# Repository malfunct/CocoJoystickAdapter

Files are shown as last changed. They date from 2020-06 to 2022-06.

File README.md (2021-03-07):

# CocoJoystickAdapter
Adapter to connect USB devices, such as gamepad or mouse,  to Tandy Color Computer joystick port.

Gerbers for shield PCB available in Shield Eagle Project directory. I have used https://jlcpcb.com/ to produce the boards in the past but any board house should be fine.

Components for the shield are listed in PartsList.txt

Arduino code for wireless xbox 360 controllers using wireless xbox 360 USB dongle is in the XBOX_360_wireless_arduino_code directory

Arduino code for wired xbox 360 controllers is in the XBOX_360_arduino_code directory

Make sure you have the libraries listed in Dependencies.txt installed for your Arduino IDE as well as configuring it for Arduino Uno R3 then open the correct ino file (wired or wireless) to match the controller you plan to use and compile and push to your Arduino Uno R3.

I assemble the shields with arduino on the bottom, USB sheild next and Coco Joystick shield on top. I power the arduino through the USB-B connector on the R3 board, plug my xbox controller into the USB sheild and use a straight through 6 pin din to 6 pin din cable to connect the adapter to the coco. A Commodore IEC cable works well for this purpose and are easy to find pre-built.

Have fun with your Coco!

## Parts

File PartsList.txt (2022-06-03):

1 - 61PC6F female DIN-6 connector
1 - TLP222A-2 dual solid state relay
1 - MCP4922 dual channel 12bit DAC with SPI
1 - 0.1uF ceramic capcitor
2 - 130 ohm 1/8 watt resistor
1 - 14 pin DIP socket
1 - 8 pin DIP socket
2 - 6 pin single row arduino stackable shield header
2 - 8 pin single row arduino stackable shield header
1 - Arduino Uno R3 (or clone)
1 - Keyes USB Host Shield https://www.fasttech.com/product/1144300-keyes-usb-host-shield-for-arduino (other brands did not work for me)

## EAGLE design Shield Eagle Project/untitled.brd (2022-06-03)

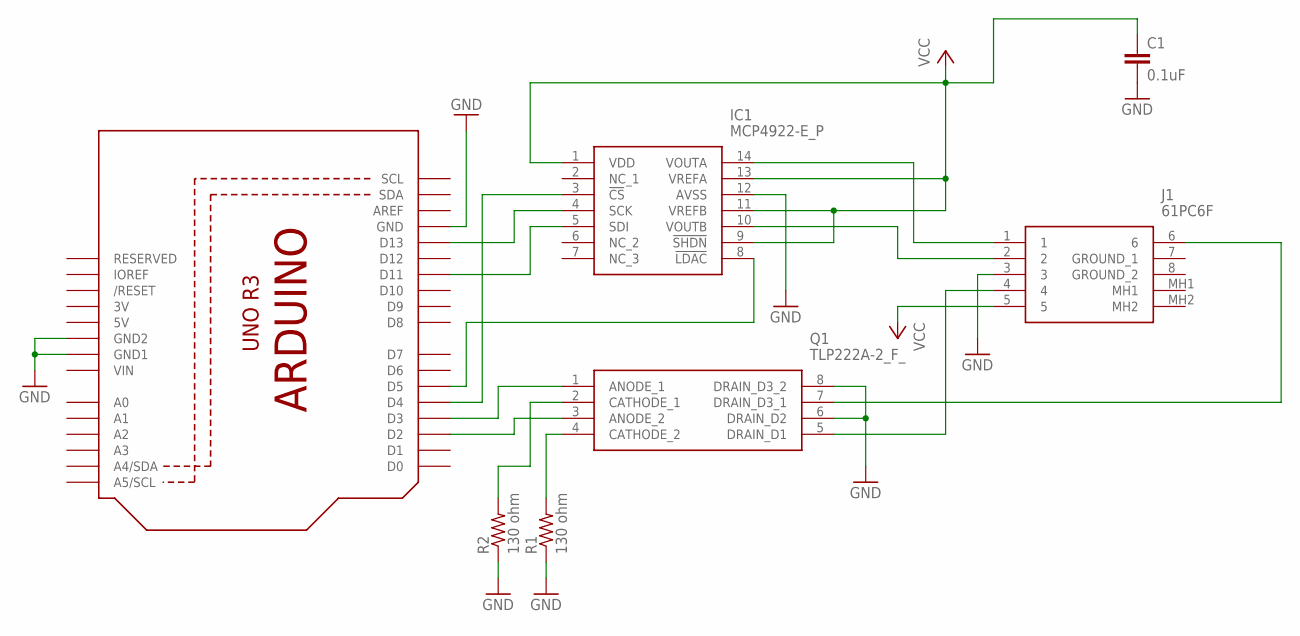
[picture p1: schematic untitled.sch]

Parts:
C1: 0.1uF; C050-024X044
IC1: MCP4922-E_P; DIP794W56P254L1905H432Q14N
J1: 61PC6F
Q1: TLP222A-2_F_; DIP762W60P254L966H485Q8N
R1, R2: 130 ohm; 0207/7
U1: ARDUINOR3-BPLACE

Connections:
3V: U1.3V
5V: U1.5V
GND: C1.2, IC1.12 (AVSS), J1.3, Q1.6 (DRAIN_D2), Q1.8 (DRAIN_D3_2), R1.1, R2.1, U1.GND, U1.GND1, U1.GND2
unnamed: IC1.4 (SCK), U1.D13
unnamed: IC1.5 (SDI), U1.D11
unnamed: Q1.4 (CATHODE_2), R1.2
unnamed: IC1.3 (!CS), U1.D4
unnamed: IC1.8 (!LDAC), U1.D5
unnamed: Q1.2 (CATHODE_1), R2.2
unnamed: Q1.1 (ANODE_1), U1.D3
unnamed: Q1.3 (ANODE_2), U1.D2
unnamed: J1.6, Q1.7 (DRAIN_D3_1)
unnamed: J1.4, Q1.5 (DRAIN_D1)
unnamed: IC1.14 (VOUTA), J1.1
unnamed: IC1.10 (VOUTB), J1.2
VCC: C1.1, IC1.1 (VDD), IC1.9 (!SHDN), IC1.11 (VREFB), IC1.13 (VREFA), J1.5
VIN: U1.VIN

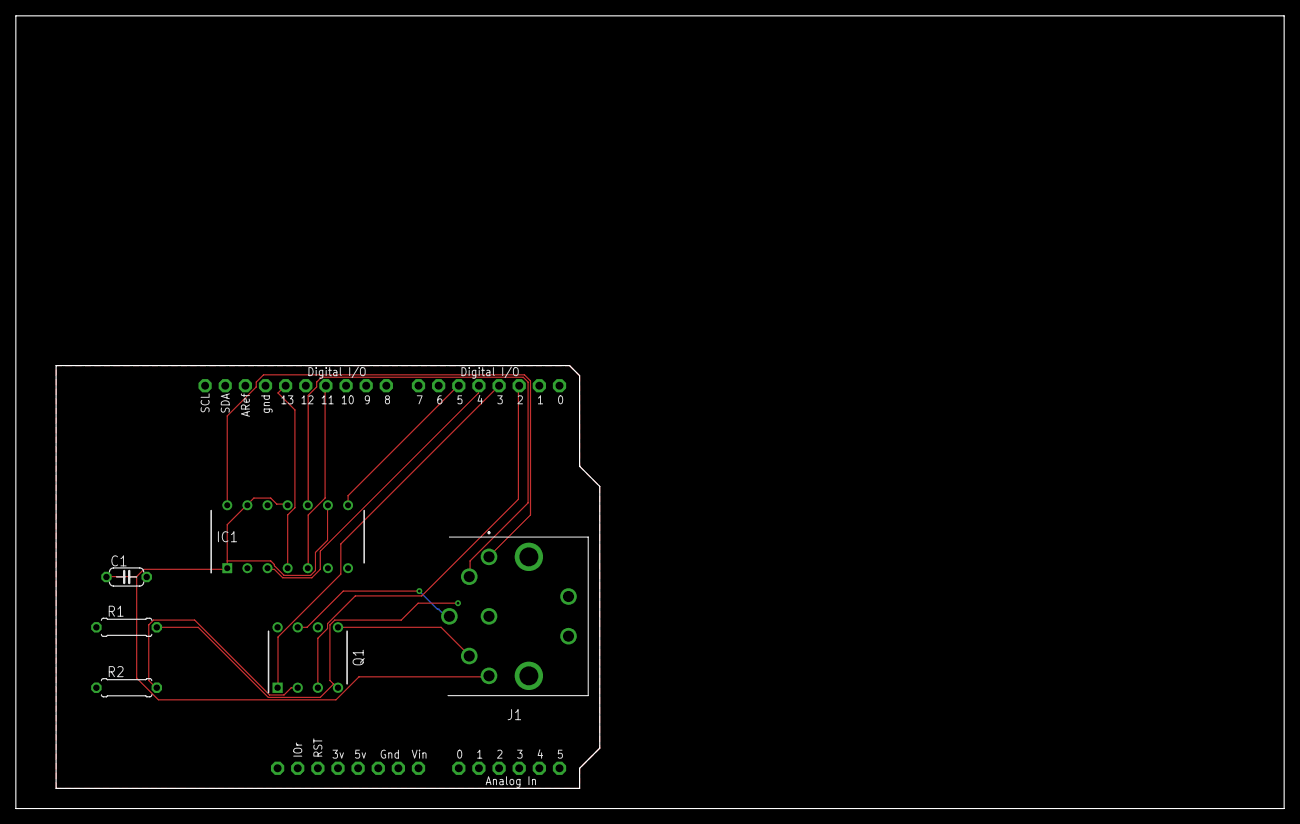
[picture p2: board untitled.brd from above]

Board: 2 copper layers, 160.0 x 100.0 mm, 7 parts (0 on the bottom side), 14 nets.

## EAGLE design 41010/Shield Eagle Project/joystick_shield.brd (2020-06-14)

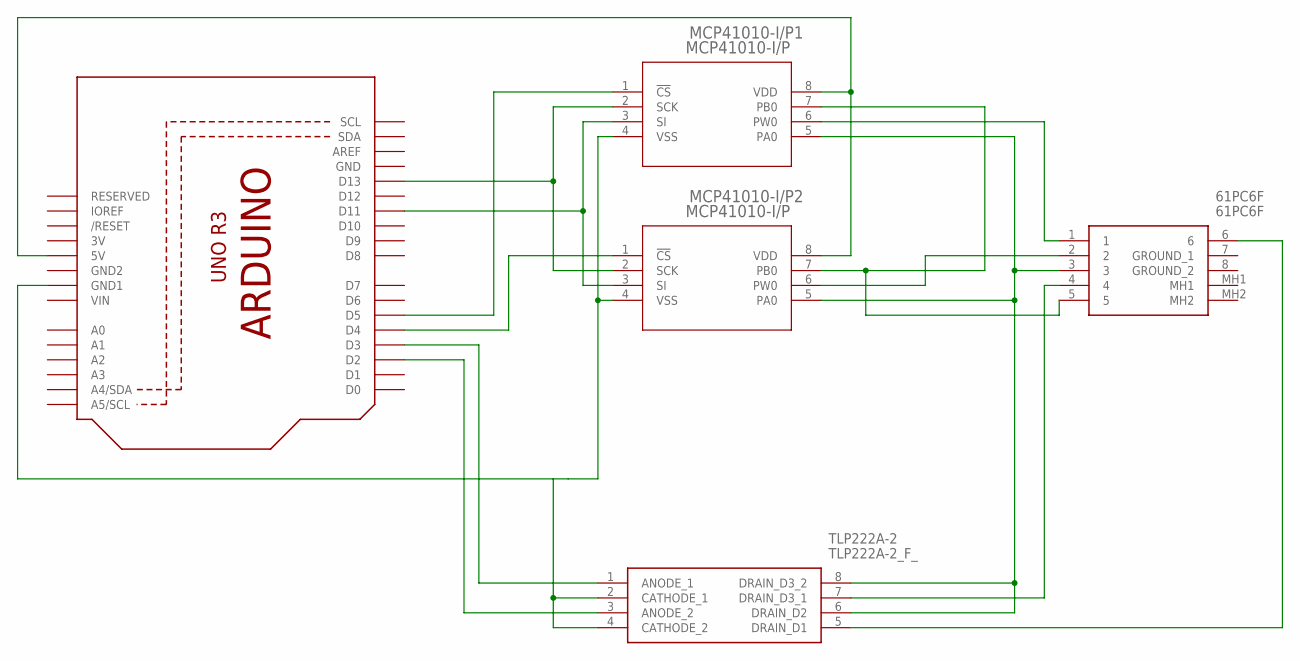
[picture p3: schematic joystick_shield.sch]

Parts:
61PC6F: 61PC6F
MCP41010-I/P1, MCP41010-I/P2: MCP41010-I/P; PDIP8_300MC
TLP222A-2: TLP222A-2_F_; DIP762W60P254L966H485Q8N
U3: ARDUINOR3-BPLACE

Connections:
3V: U3.3V
GND: U3.GND
GND2: U3.GND2
unnamed: MCP41010-I/P1.2 (SCK), MCP41010-I/P2.2 (SCK), U3.D13
unnamed: MCP41010-I/P2.1 (!CS), U3.D4
unnamed: MCP41010-I/P1.3 (SI), MCP41010-I/P2.3 (SI), U3.D11
unnamed: MCP41010-I/P1.4 (VSS), MCP41010-I/P2.4 (VSS), TLP222A-2.2 (CATHODE_1), TLP222A-2.4 (CATHODE_2), U3.GND1
unnamed: MCP41010-I/P1.1 (!CS), U3.D5
unnamed: TLP222A-2.1 (ANODE_1), U3.D3
unnamed: MCP41010-I/P1.8 (VDD), MCP41010-I/P2.8 (VDD), U3.5V
unnamed: TLP222A-2.3 (ANODE_2), U3.D2
unnamed: 61PC6F.3, MCP41010-I/P1.5 (PA0), MCP41010-I/P2.5 (PA0), TLP222A-2.6 (DRAIN_D2), TLP222A-2.8 (DRAIN_D3_2)
unnamed: 61PC6F.4, TLP222A-2.7 (DRAIN_D3_1)
unnamed: 61PC6F.5, MCP41010-I/P1.7 (PB0), MCP41010-I/P2.7 (PB0)
unnamed: 61PC6F.6, TLP222A-2.5 (DRAIN_D1)
unnamed: 61PC6F.2, MCP41010-I/P2.6 (PW0)
unnamed: 61PC6F.1, MCP41010-I/P1.6 (PW0)
VIN: U3.VIN

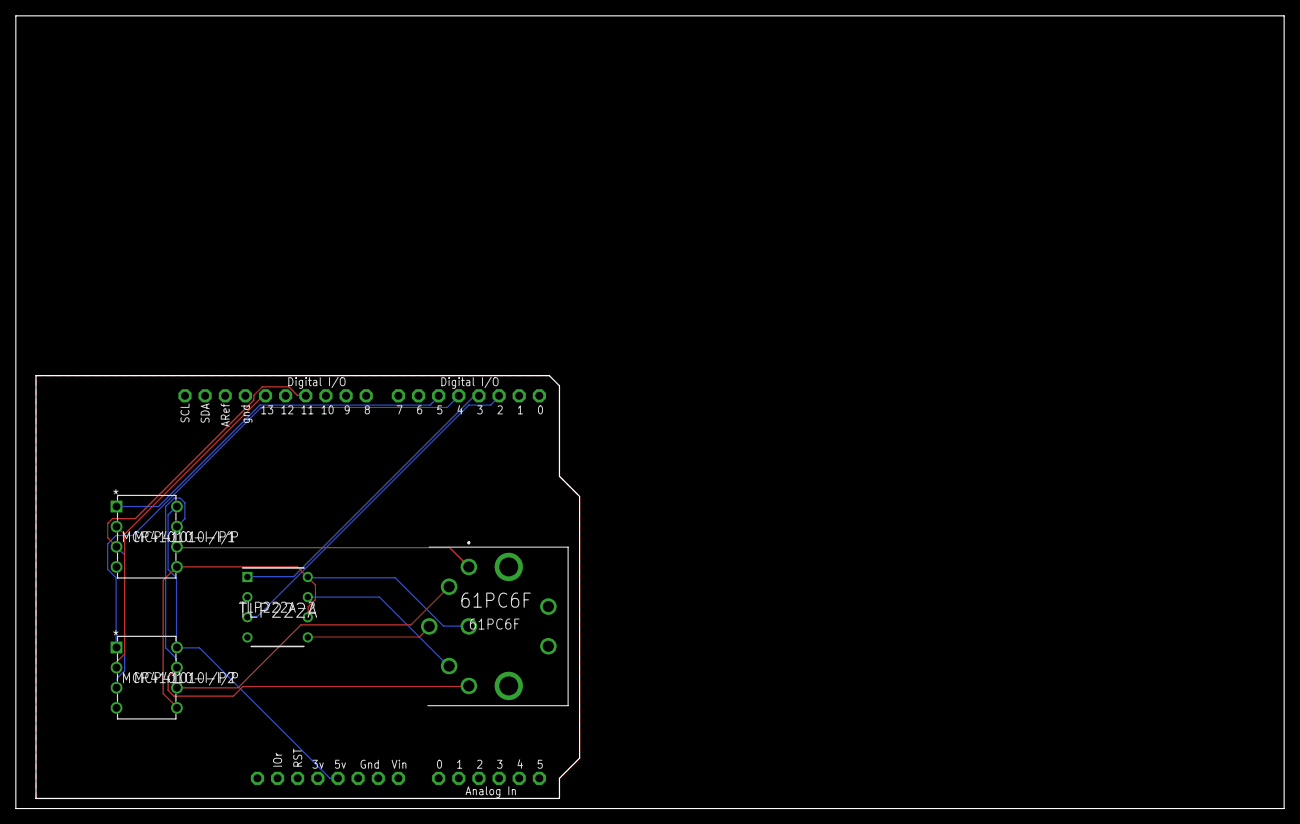
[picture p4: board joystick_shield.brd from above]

Board: 2 copper layers, 160.0 x 100.0 mm, 5 parts (0 on the bottom side), 14 nets.

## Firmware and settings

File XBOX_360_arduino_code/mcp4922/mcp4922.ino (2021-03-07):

#include <XBOXUSB.h>

// Satisfy the IDE, which needs to see the include statment in the ino too.
#ifdef dobogusinclude
#include <spi4teensy3.h>
#endif

#include <SPI.h>
#include <DAC_MCP49xx.h>


USB Usb;
XBOXUSB Xbox(&Usb);

const int CS = 4;
const int LDAC = 5;
int BUTTON1 = 2;
int BUTTON2 = 3;

DAC_MCP49xx dac(DAC_MCP49xx::MCP4922, CS, LDAC);

void setup() {  
  Serial.begin(115200);
  
  if (Usb.Init() == -1) {
    Serial.print("Failed.");
    while (1); //halt
  }
  
  dac.setSPIDivider(SPI_CLOCK_DIV16);
  pinMode(BUTTON1,OUTPUT);
  pinMode(BUTTON2,OUTPUT);
}

void loop() {
  Usb.Task();
  if (Xbox.Xbox360Connected) {
    int leftHatX = Xbox.getAnalogHat(LeftHatX);
    int leftHatY = Xbox.getAnalogHat(LeftHatY);

    int rightHatX = Xbox.getAnalogHat(RightHatX);
    int rightHatY = Xbox.getAnalogHat(RightHatY);

    // if you are using only the right stick replace
    // left stick values with right stick values to
    // enable the use of either stick
    if(abs(rightHatX) > 4000 && abs(leftHatX) <= 4000)
    {
      leftHatX == rightHatX;
    }

    if(abs(rightHatY) > 4000 && abs(leftHatY) <= 4000)
    {
      leftHatY == rightHatY;
    }

    // create a dead zone in the middle
    if(leftHatX < 0) {leftHatX += 4000; if(leftHatX > 0) leftHatX = 0;}
    if(leftHatX > 0) {leftHatX -= 4000; if(leftHatX < 0) leftHatX = 0;}
    if(leftHatY < 0) {leftHatY += 4000; if(leftHatY > 0) leftHatY = 0;}
    if(leftHatY > 0) {leftHatY -= 4000; if(leftHatY < 0) leftHatY = 0;}

    // allow corners to be max/max, introduces dead zones top, bottom, left, right
    if(leftHatX > 18000) leftHatX = 18000;
    if(leftHatX < -18000) leftHatX = -18000;
    if(leftHatY > 18000) leftHatY = 18000;
    if(leftHatY < -18000) leftHatY = -18000;

    int up = Xbox.getButtonPress(UP);
    int down = Xbox.getButtonPress(DOWN);
    int left = Xbox.getButtonPress(LEFT);
    int right = Xbox.getButtonPress(RIGHT);

    if(up)
    {
      leftHatY = 18000;
    }

    if(down)
    {
      leftHatY = -18000;
    }

    if(right)
    {
      leftHatX = 18000;
    }

    if(left)
    {
      leftHatX = -18000;
    }
    
    Serial.print("X hat: ");
    Serial.print(leftHatX);
    Serial.print(" Y hat: ");
    Serial.print(leftHatY);

    int aButton = Xbox.getButtonPress(A);
    int bButton = Xbox.getButtonPress(B);
    int xButton = Xbox.getButtonPress(X);
    int yButton = Xbox.getButtonPress(Y);

    int leftTrigger = Xbox.getButtonPress(L2);
    int rightTrigger = Xbox.getButtonPress(R2);

    int tandyX = map(leftHatX,-18000,18000,0,4095);
    int tandyY = 4095 - map(leftHatY,-18000,18000,0,4095);
    
    Serial.print(" TandyX: ");
    Serial.print(tandyX);
    Serial.print(" TandyY: ");
    Serial.print(tandyY);
    
    int press1=LOW;
    int press2=LOW;
    if(aButton or xButton or rightTrigger)
    {
      press1=HIGH;
    }
    if(bButton or yButton or leftTrigger)
    {
      press2=HIGH;
    }

    if(press1 == HIGH)
    {
      Serial.print(" Button 1");
    }

    if(press2 == HIGH)
    {
      Serial.print(" Button 2");
    }

    Serial.println("");
  
    dac.output2(tandyX,tandyY);
    dac.latch();
    digitalWrite(BUTTON1,press1);
    digitalWrite(BUTTON2,press2);
  }
  else
  {
    Serial.println("not connected");
  }
}

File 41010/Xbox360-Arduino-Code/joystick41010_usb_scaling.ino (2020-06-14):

#include <XBOXUSB.h>
#define ENABLE_UHS_DEBUGGING 1

// Satisfy the IDE, which needs to see the include statment in the ino too.
#ifdef dobogusinclude
#include <spi4teensy3.h>
#endif

#include <SPI.h>

USB Usb;
XBOXUSB Xbox(&Usb);

int SS0 = 4;
int SS1 = 5;
int button1 = 3;
int button2 = 2;

void setup() {
  if (Usb.Init() == -1) {
    while (1); //halt
  }
  
  pinMode (SS0, OUTPUT);
  pinMode (SS1, OUTPUT);
  digitalWrite(SS0, HIGH);
  digitalWrite(SS1, HIGH);
  SPI.begin();
  SPI.setClockDivider(SPI_CLOCK_DIV128);
  pinMode(button1,OUTPUT);
  pinMode(button2,OUTPUT);

//  Serial.begin(9600);
}

void loop() {
  Usb.Task();
  if (Xbox.Xbox360Connected) {
    int leftHatX = Xbox.getAnalogHat(LeftHatX);
    int leftHatY = Xbox.getAnalogHat(LeftHatY);

    // create a dead zone in the middle
    if(leftHatX < 0) {leftHatX += 4000; if(leftHatX > 0) leftHatX = 0;}
    if(leftHatX > 0) {leftHatX -= 4000; if(leftHatX < 0) leftHatX = 0;}
    if(leftHatY < 0) {leftHatY += 4000; if(leftHatY > 0) leftHatY = 0;}
    if(leftHatY > 0) {leftHatY -= 4000; if(leftHatY < 0) leftHatY = 0;}

    // allow corners to be max/max, introduces dead zones top, bottom, left, right
    if(leftHatX > 18000) leftHatX = 18000;
    if(leftHatX < -18000) leftHatX = -18000;
    if(leftHatY > 18000) leftHatY = 18000;
    if(leftHatY < -18000) leftHatY = -18000;
    
//    Serial.print("X hat: ");
//    Serial.print(leftHatX);
//    Serial.print(" Y hat: ");
//    Serial.println(leftHatY);

    int aButton = Xbox.getButtonPress(A);
    int bButton = Xbox.getButtonPress(B);
    int xButton = Xbox.getButtonPress(X);
    int yButton = Xbox.getButtonPress(Y);

    int tandyX = 255 - map(leftHatX,-18000,18000,0,255);
    int tandyY = map(leftHatY,-18000,18000,0,255);
    
//    Serial.print("TandyX: ");
//    Serial.print(tandyX);
//    Serial.print(" TandyY: ");
//    Serial.println(tandyY);
    
    int press1=LOW;
    int press2=LOW;
    if(aButton or xButton)
    {
      press1=HIGH;
    }
    if(bButton or yButton)
    {
      press2=HIGH;
    }

    MCP41010Write(tandyX,SS1);
    MCP41010Write(tandyY,SS0);
    digitalWrite(button1,press1);
    digitalWrite(button2,press2);
  }
}

void MCP41010Write(byte value, int p)
{  // Note that the integer vale passed to this subroutine
  // is cast to a byte

  digitalWrite(p, LOW);
  SPI.transfer(B00010001); // This tells the chip to set the pot
  SPI.transfer(value);     // This tells it the pot position
  digitalWrite(p, HIGH);
}

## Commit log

2020-06-14 Adding arduino project for Xbox360 controller software.
2020-06-14 Add eagle file for 41010 based arduino shield
    [joystick_shield.brd, joystick_shield.sch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]
2020-06-24 add sketch for mcp4922 based board.
2020-06-24 Adding EAGLE files for 4922 based shield.
    [copper_bottom.gbr, copper_top.gbr, drill_1_16.xln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]
2020-07-24 Update to latest eagle files.
    [copper_top.gbr, drill_1_16.xln]
2020-09-19 Initial commit of xbox wireless controller version of software.
2021-03-07 Updated parts list with URL to USB Host Shield and added dependancy list for building arduino source.
2021-03-07 Reogranized to make active code easier to find.
    [joystick_shield.brd, joystick_shield.sch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]
2022-05-18 Add current limiting resistor for SSR to meet spec.
    [untitled.brd, untitled.sch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]
2022-05-19 Adding resistor to parts list to match new schematic
2022-05-19 Fixing typo in resistor value from 103 to the correct 130 ohm.
2022-05-23 First draft of 'dual shooter' design
    [untitled.brd, untitled.sch]
2022-06-03 Using individual resistors between opto isolator and ground to avoid under current conditions that might have happened otherwise.
    [untitled.brd, untitled.sch]

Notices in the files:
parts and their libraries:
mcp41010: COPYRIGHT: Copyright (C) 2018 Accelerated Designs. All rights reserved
